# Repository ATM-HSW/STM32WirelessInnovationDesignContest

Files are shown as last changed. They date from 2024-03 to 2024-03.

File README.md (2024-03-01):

# STM32 Wireless Innovation Design Contest

## Universal room sensor for various MCUs with communication interfaces

### Teaser:

As part of this project, a multi-sensor module is being developed with which various room parameters can be measured. In addition to the usual measured values of temperature, humidity and air pressure, the indoor air quality is also to be determined using VOC and CO2 sensors. A multi-channel light measurement is also to be carried out.

The sensor module should be as compact as possible and be able to be used universally on various MCU platforms via the I2C bus.

Programming should be as simple as possible using existing libraries and software environments, e.g. Arduino environment, Micro- or CircuitPython.

The choice in this competition fell on the relatively new STM32WB52xx platform. Experience with other STM Nucleo boards forms the basis for this project.

### Project Details

The universal room sensor is being developed as the most universal platform possible to measure the parameters of the environment, i.e. rooms such as a lecture theatres, seminar rooms or offices. It should also be possible to test different MCU variants with different communication interfaces and different software environments.

The aim is to equip the rooms of a university with the room sensor. Staff and students should be able to access the sensor values. In future, however, it should also be possible to use the values for needs-based and energy-efficient control of the rooms and integration into the Building Information Management (BIM) system.

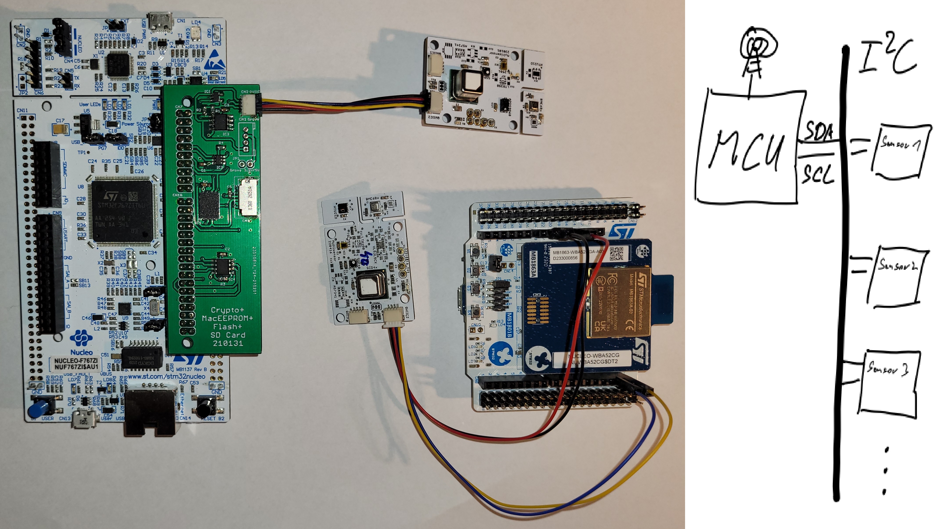
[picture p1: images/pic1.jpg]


### System Overview

As the chosen platform Nucleo-WBA52 is still relatively new, the software support is not yet as extensive as with hardware platforms that have been available for longer. The aim of this project is not the direct use of STM's Cube Packages but of development environments such as Arduino and Circuit-/Micropython. The Python variants are not yet available at the release date 01.03.2024. The Arduino platform STM32duino [sta1] has contained the extension for the STM32WBA family in the main branch since 29/02/2024. However, the planned release 2.8 is not yet available at the time of publication. According to the instructions [sta2], however, a Git branch can also be used for development.

In order to be able to compare the implementation with Circuit- and Micropython, the MultiSensor module was used with the Nucleo-F767 platform, which has been available for some time. This platform can be used in all three environments.

A test shield from a previous project is used to connect the MultiSensor module to the Nucleo-F7676. Only the QWIIC (I2C) connector is used. To connect to the Nucleo-WBA52, a shield has been developed that only provides a QWIIC connector. Due to component availability, the design only includes a short socket strip on which the 3.3V connection is missing. Therefore a 3.3V LDO is used on the board. As this board could not be finalised at the time of publication, a standard QWIIC cable with male jumpers is used to connect the Nucleo board with the MultiSensor module.

Both adapter boards were designed with eagle. The CAD data is available in the project repository at Github (link under software used)

### Sensor hardware

The MultiSensor module contains various sensors for measuring environmental parameters. All sensors are connected to the MCU via an I2C bus. The sensors were selected based on the availability of the ICs and the availability of open source drivers for the development environments analysed. The I2C bus can be used in two ways: on a pin header and via dual QUIIC sockets. As there is an overlap between the I2C addresses of the APDS9960 and AS7341 light sensors, two I2C buses are used. However, both buses are connected by default via solder jumpers. The two solder jumpers only need to be disconnected if both light sensors are to be used. In this case, the APDS9960 is no longer available at the QWIIC sockets, but only via the pin headers.

The only special mechanical feature of the board layout is the thermal decoupling of the two temperature sensors BME680 and HTU21 on the left-hand side of the board.

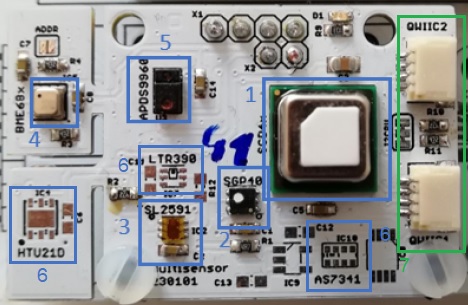
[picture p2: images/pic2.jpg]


- Sensor 1: CO2 sensor SCD4x

The SCD-4x CO2 sensors from Sensirion have a measuring range of 400-5000 ppm with different accuracies between ±40 and ±75ppm, depending on the exact type. Versions 40, 41 and 42 are pin and software compatible. As the sensor is based on a photoacoustic measuring principle, it is relatively small and energy-saving compared to older sensors based on the non-dispersive infrared sensor principle [MP]. The ambient air in the measuring chamber is irradiated with a defined light pulse (wavelength approx. 4.3µm). The gas molecules absorb the light. The result is an increase in pressure in the measuring cell. The increase in pressure generates sound waves that can be picked up by a microphone.

For good indoor air quality, the CO2 value should be below 800ppm. The maximum guideline value for indoor spaces is 1500ppm [CIK]. At this value, signs of fatigue can already occur.

- Sensor 2: SGP4x

The SGP-40 and 41 indoor air quality sensors from Sensirion measure volatile organic compounds (VOCs) such as sweat, urea, paint and cleaning agents. The 41 model can also detect nitrogen oxides (NOx). The sensor is a chemical metal oxide semiconductor gas sensor. The surface of the sensor that comes into contact with the gas to be detected is coated with a metal oxide. This changes its resistance, which can be read out as a raw value.

The raw value of the sensor is mapped by a filter function to a measuring range of 0-500, the IAQ index. A value of 100 corresponds to uncontaminated room air.

- Sensor 3: TSL2591 light sensor

The measuring principle of the TSL2591 light sensor from ams is based on two light-to-digital converters that convert the incoming light intensity into electrical signals using photodiodes. The light irradiation changes the electrical voltage measured by the photodiode or the current flowing through the diode. The sensor's two photodiodes measure the part of the light visible to humans and the infrared spectrum in two channels.

- Sensor 4: Temperature, humidity, pressure and gas sensor BME680

The BME680 combination sensor from Bosch is a MEMS sensor that measures the ambient air parameters of temperature, humidity and air pressure. A gas sensor is also included.

- Sensor 5: APDS9960 light sensor

Like sensor 3, the APDS9960 light sensor from Avago can measure light intensity. Colour measurement is also possible. However, in this project the sensor is used for contactless operation, as it can also be used as a proximity sensor and for gesture recognition such as UP-DOWN-RIGHT-LEFT.

- Sensors 6:

The photo shows an assembly variant in which other sensors have not been fitted. The HTU21 is a sensor for temperature and humidity comparable to the BME680. Ambient light measurement can be extended with the two light sensors LTR390 and AS7341. The LTR390 can measure ultraviolet light in two spectra. The AS7341 is sensitive in the visible and near IR range, similar to the TSL2561, but is divided into 11 channels so that colour temperatures can also be determined.

The circuit and layout were designed using eagle. The respective data sheet information and open hardware layouts were generally used from the Adafruit Github account [ada]. The CAD data is available in the project repository at Github (link under Software used)

The CAD data is available on the car's Github account. The hardware is fully tested, including the sensors missing in the figure above.

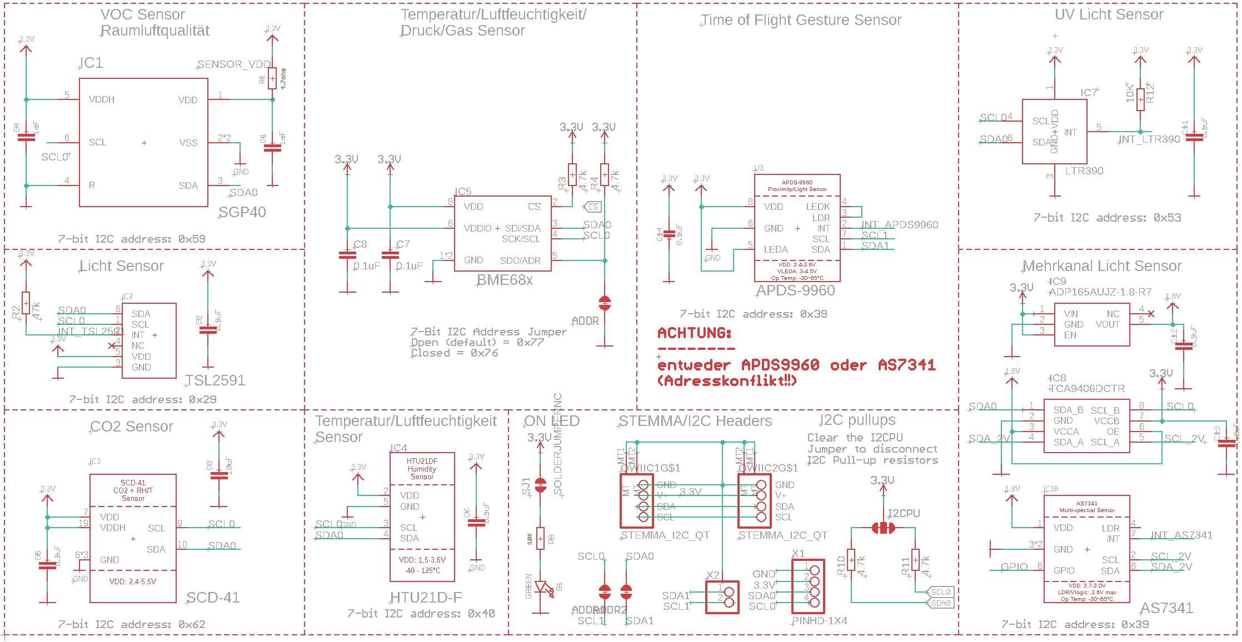
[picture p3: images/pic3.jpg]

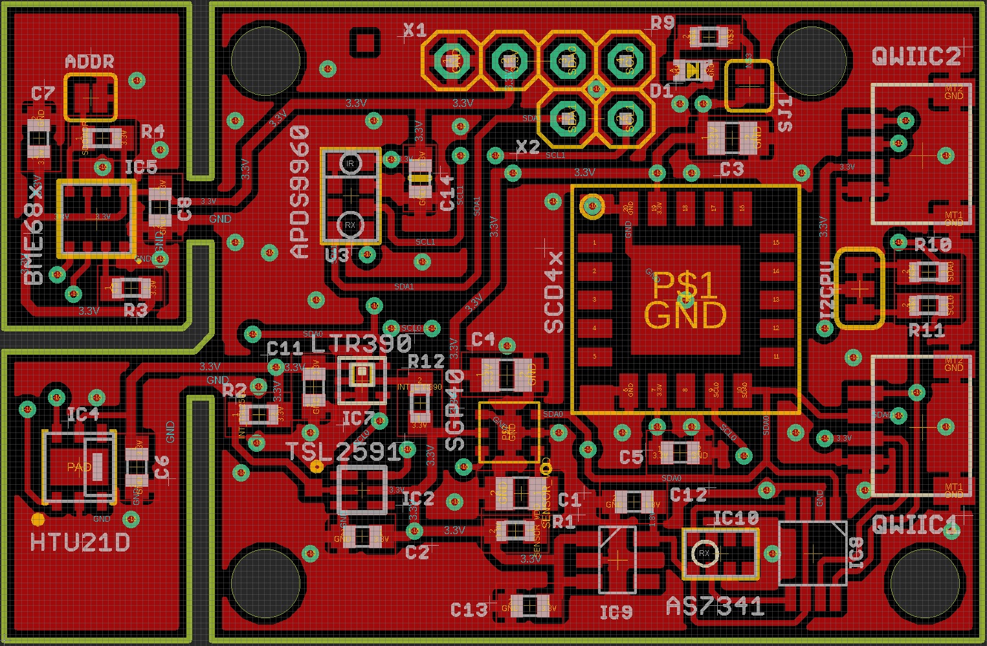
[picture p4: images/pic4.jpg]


### Software

- Variant 1: Nucleo-F767 and Micropython

The implementation with Micropython is only a proof of concept due to limitations of the current Micropython implementation. Usable libraries exist for the BME680, HTU21, SGP40 and SCP4x sensors. The Ethernet interface is directly supported by Micropython. A connection to Thingsboard as an IOT cloud is possible.

As expected, the implementation under Micropython is very quick and easy. The firmware can be flashed with the onboard ST-Link. Utilising existing libraries, the sensors are ready for operation in a short time.

However, the division of the flash has proved to be a significant disadvantage. With the default setting. Of the 2Mbyte flash, only around 80kByte are available for Python code. Most of the rest is reserved for the firmware, although this amount is far from being required.

- Variant 2: Nucleo-F767 and Circuitpython

The statements made about variant 1 also apply to variant 2. As essentially only sensors that are also sold by Adafruit are used, the software support is even simpler than under Micropython. However, the same restriction also applies to Circuitpython: the flash size for the Python sources is too small. Another disadvantage is the lack of network support.

#### Summary of variants 1 and 2:

If it were not for the limitation of the flash size, Micro- and Circuitpython could be very good development environments for the use of the MultiSensor. The lack of Ethernet support in Circuitpython is an exclusion criterion if a cloud connection is required.

The MultiSensor, including a cloud connection, could be fully implemented with another MCU platform using the Circuitpyhon environment.

Porting for the NUCLEO-WBA52 platform has not yet taken place, but it can be assumed that this platform can also be used very well under Python. The disadvantage of the flash size is solvable, as there is sufficient unused flash memory available.

- Variant 3: Nucleo-F767 and STM32duino

As the port for the STM32WBAxx family was not yet available at the start of the project, an initial implementation was carried out on the Nucleo-F767. Available Arduino libraries were used for the sensors. With a few minor adjustments to these libraries, all sensors could be used.

- Variant 4: Nucleo-WBA52 and STM32duino

The application developed for variant 3 could be used directly for variant 4. It was only necessary to adapt the I2C pins.

#### Summary of variants 3 and 4:

As the Arduino environment has existed for a very long time, there are many examples, drivers etc. available. Not everything is immediately usable. But changes are usually limited. Due to the unavoidable compile-link-flash cycle, development is significantly less agile than with a Python variant. However, the usage is also possible with an acceptable amount of effort.

The sources of the implementations are available in the project repository at Github (link under Software used).

## Literature:

[ad] Adafruit Industries, LLC. url: www.adafruit.com

[cik] CIK Solutions. Kohlenstoffdioxid in Räumen messen und überwachen. url: https://www.cik-solutions.com/anwendungen/co2-im-innenraum/

[mp] MIROSLAV PISKOR. SCD4x – der kleinste CO2-Sensor. Hrsg. von SOS electronic. 2021-04-15. url: https://www.soselectronic.com/de/articles/sensirion/scd4x-der-kleinste-co2-sensor-2559

[sta1] STM32duino project repository. url: https://github.com/stm32duino

[sta2] STM32duino git repo integratio into Arduino IDE. url: https://github.com/stm32duino/Arduino_Core_STM32/wiki/Using-git-repository

## Used Software

STM32duino

https://github.com/stm32duino/Arduino_Core_STM32/archive/a5135d476018c1d1ea7b33afe86ae29aa416cbf7.zip

Circuitpython

https://downloads.circuitpython.org/bin/nucleo_f767zi/de_DE/adafruit-circuitpython-nucleo_f767zi-de_DE-8.2.10.bin

Micropython

https://micropython.org/resources/firmware/NUCLEO_F767ZI-20240222-v1.22.2.hex

Project sourcen

https://github.com/ATM-HSW/STM32WirelessInnovationDesignContest

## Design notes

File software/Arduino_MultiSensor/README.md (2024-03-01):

Used Libraries:

HTU21: https://github.com/adafruit/Adafruit_HTU21DF_Library (v1.1.2)
BME68x: https://github.com/adafruit/Adafruit_BME680 (v2.0.4)
SGP40: https://github.com/adafruit/Adafruit_SGP40 (v1.1.3)
SCD40: https://github.com/Sensirion/arduino-i2c-scd4x (v0.4.0)
TSL2591: https://github.com/adafruit/Adafruit_TSL2591_Library (v1.4.5)

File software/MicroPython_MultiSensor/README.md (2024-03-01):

Used Libraries:

HTU21: https://github.com/Kleity/HTU21D-Micropython-ESP32
BME68x: https://github.com/robert-hh/BME680-Micropython
SGP40: https://github.com/agners/micropython-sgp40
SCD40: https://github.com/mikan/rpi-pico-scd4x

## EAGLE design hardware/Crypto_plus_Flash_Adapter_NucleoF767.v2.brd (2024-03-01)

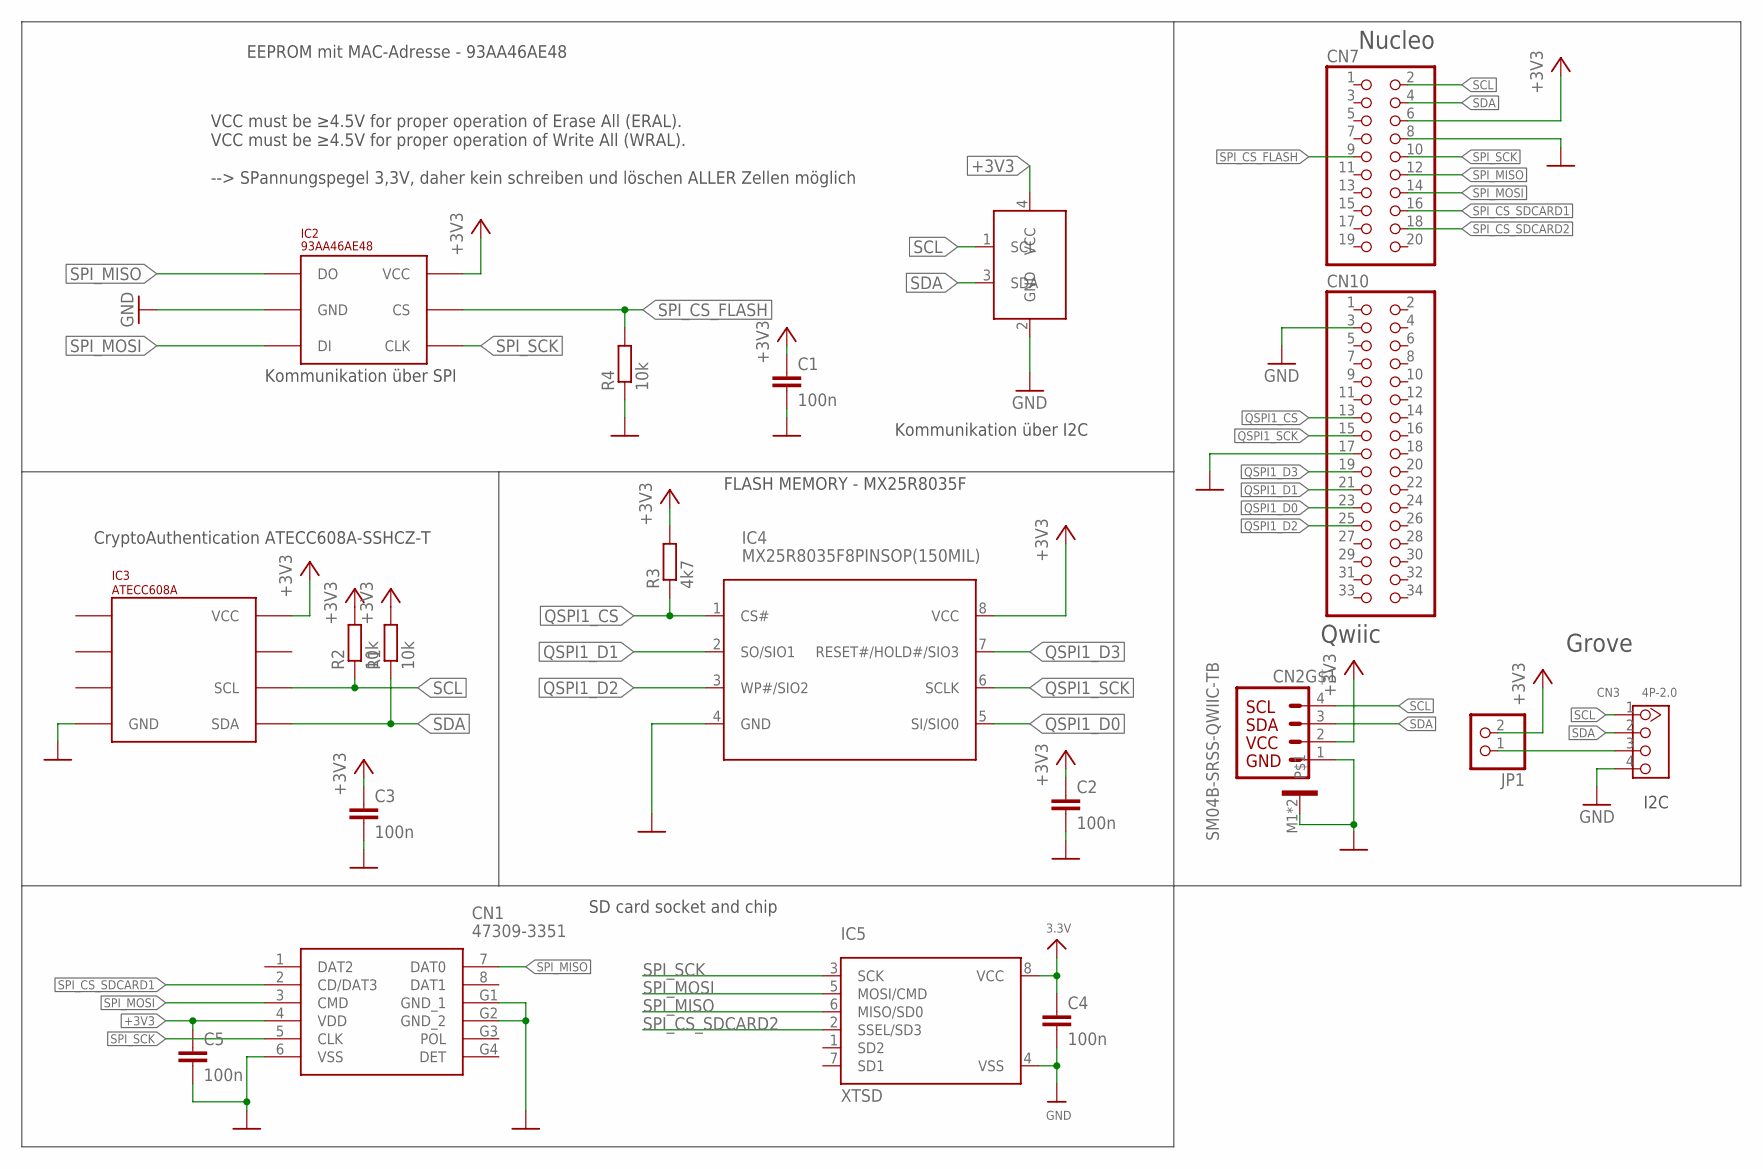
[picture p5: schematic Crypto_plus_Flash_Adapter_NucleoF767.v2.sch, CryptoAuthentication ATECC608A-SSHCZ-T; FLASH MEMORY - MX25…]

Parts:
C1, C2, C3, C4, C5: 100n; C0603
CN1: 47309-3351; 473093351
CN2: SM04B-SRSS-QWIIC-TB; SM04B-SRSS-TB
CN3: 4P-2.0; HW4-2.0
CN7: PINHD-2X10; 2X10
CN10: PINHD-2X17; 2X17
IC1: I2CEEPROM_24AA02E48; SOT23-5L
IC2: 93AA46AE48
IC3: ATECC608A; SOIC8
IC4: MX25R8035F8PINSOP(150MIL); SOIC127P600X175-8
IC5: XTSD; LGA8_8X6
JP1: PINHD-1X2; 1X02
R1, R2, R4: 10k; R0603
R3: 4k7; R0603

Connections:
+3V3: C1.1, C2.1, C3.1, C4.1, C5.1, CN1.4 (VDD), CN2.2, CN7.6, IC1.4 (VCC), IC2.P$6 (VCC), IC3.8 (VCC), IC4.8 (VCC), IC5.8 (VCC), JP1.2, R1.2, R2.2, R3.2
GND: C1.2, C2.2, C3.2, C4.2, C5.2, CN1.6 (VSS), CN1.G1 (GND_1), CN1.G2 (GND_2), CN2.1, CN2.M1, CN2.M2, CN3.4, CN7.8, CN10.17, IC1.2 (GND), IC2.P$2 (GND), IC3.4 (GND), IC4.4 (GND), IC5.4 (VSS), R4.1
unnamed: CN3.3, JP1.1
QSPI1_CS: CN10.13, IC4.1 (CS#), R3.1
QSPI1_D0: CN10.23, IC4.5 (SI/SIO0)
QSPI1_D1: CN10.21, IC4.2 (SO/SIO1)
QSPI1_D2: CN10.25, IC4.3 (WP#/SIO2)
QSPI1_D3: CN10.19, IC4.7 (RESET#/HOLD#/SIO3)
QSPI1_SCK: CN10.15, IC4.6 (SCLK)
SCL: CN2.4, CN3.1, CN7.2, IC1.1 (SCL), IC3.6 (SCL), R2.1
SDA: CN2.3, CN3.2, CN7.4, IC1.3 (SDA), IC3.5 (SDA), R1.1
SPI_CS_FLASH: CN7.9, IC2.P$5 (CS), R4.2
SPI_CS_SDCARD1: CN1.2 (CD/DAT3), CN7.16
SPI_CS_SDCARD2: CN7.18, IC5.2 (SSEL/SD3)
SPI_MISO: CN1.7 (DAT0), CN7.12, IC2.P$1 (DO), IC5.6 (MISO/SD0)
SPI_MOSI: CN1.3 (CMD), CN7.14, IC2.P$3 (DI), IC5.5 (MOSI/CMD)
SPI_SCK: CN1.5 (CLK), CN7.10, IC2.P$4 (CLK), IC5.3 (SCK)

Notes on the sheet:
VCC must be ≥4.5V for proper operation of Erase All (ERAL). VCC must be ≥4.5V for proper operation of Write All (WRAL). --> SPannungspegel 3,3V, daher kein schreiben und löschen ALLER Zellen möglich
Kommunikation über SPI
CryptoAuthentication ATECC608A-SSHCZ-T
FLASH MEMORY - MX25R8035F
EEPROM mit MAC-Adresse - 93AA46AE48
Kommunikation über I2C
SD card socket and chip
Qwiic
I2C
Grove
Nucleo

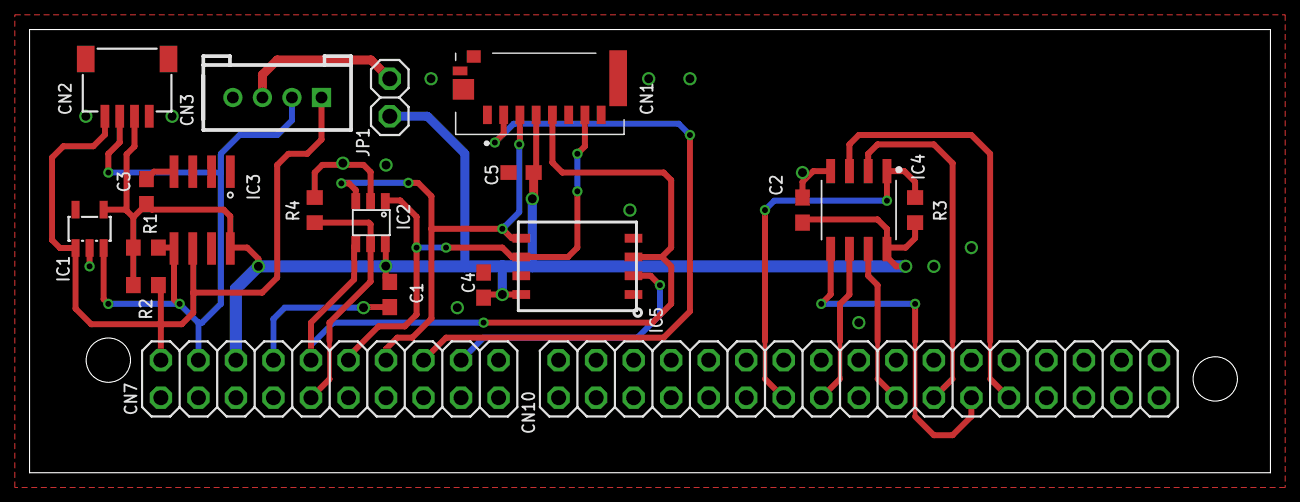
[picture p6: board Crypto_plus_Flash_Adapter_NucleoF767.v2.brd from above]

Board: 4 copper layers, 84.0 x 30.0 mm, 20 parts (0 on the bottom side), 17 nets.

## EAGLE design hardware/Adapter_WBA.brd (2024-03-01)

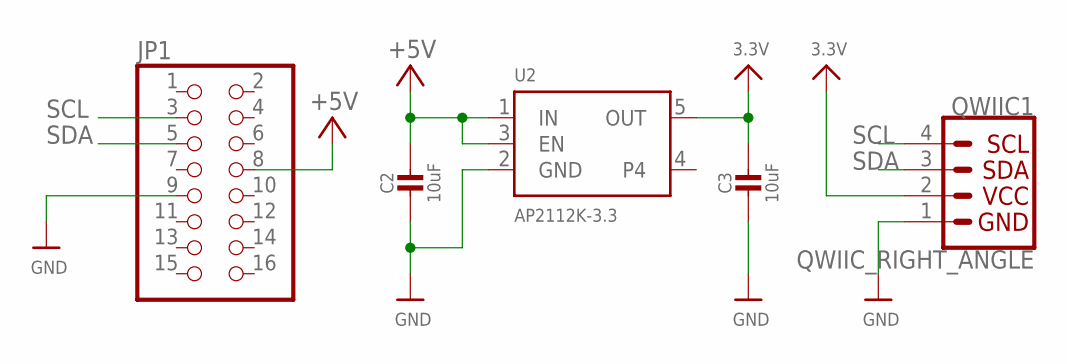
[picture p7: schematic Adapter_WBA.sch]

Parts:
C2, C3: 10uF; 0805-NO
JP1: PINHD-2X8; 2X08
QWIIC1: QWIIC_RIGHT_ANGLE; JST04_1MM_RA
U2: AP2112K-3.3; SOT23-5

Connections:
3.3V: C3.1, QWIIC1.2, U2.5 (OUT)
+5V: C2.1, JP1.8, U2.1 (IN), U2.3 (EN)
GND: C2.2, C3.2, JP1.9, QWIIC1.1, U2.2 (GND)
SCL: JP1.3, QWIIC1.4
SDA: JP1.5, QWIIC1.3

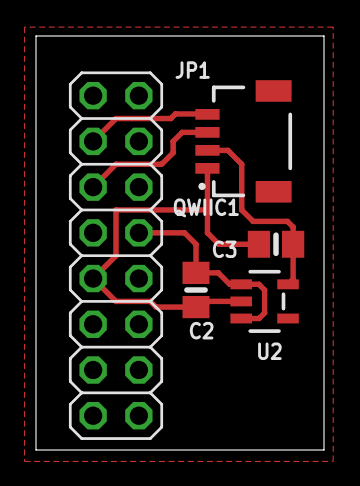
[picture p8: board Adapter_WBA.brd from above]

Board: 2 copper layers, 16.0 x 23.0 mm, 5 parts (0 on the bottom side), 5 nets.

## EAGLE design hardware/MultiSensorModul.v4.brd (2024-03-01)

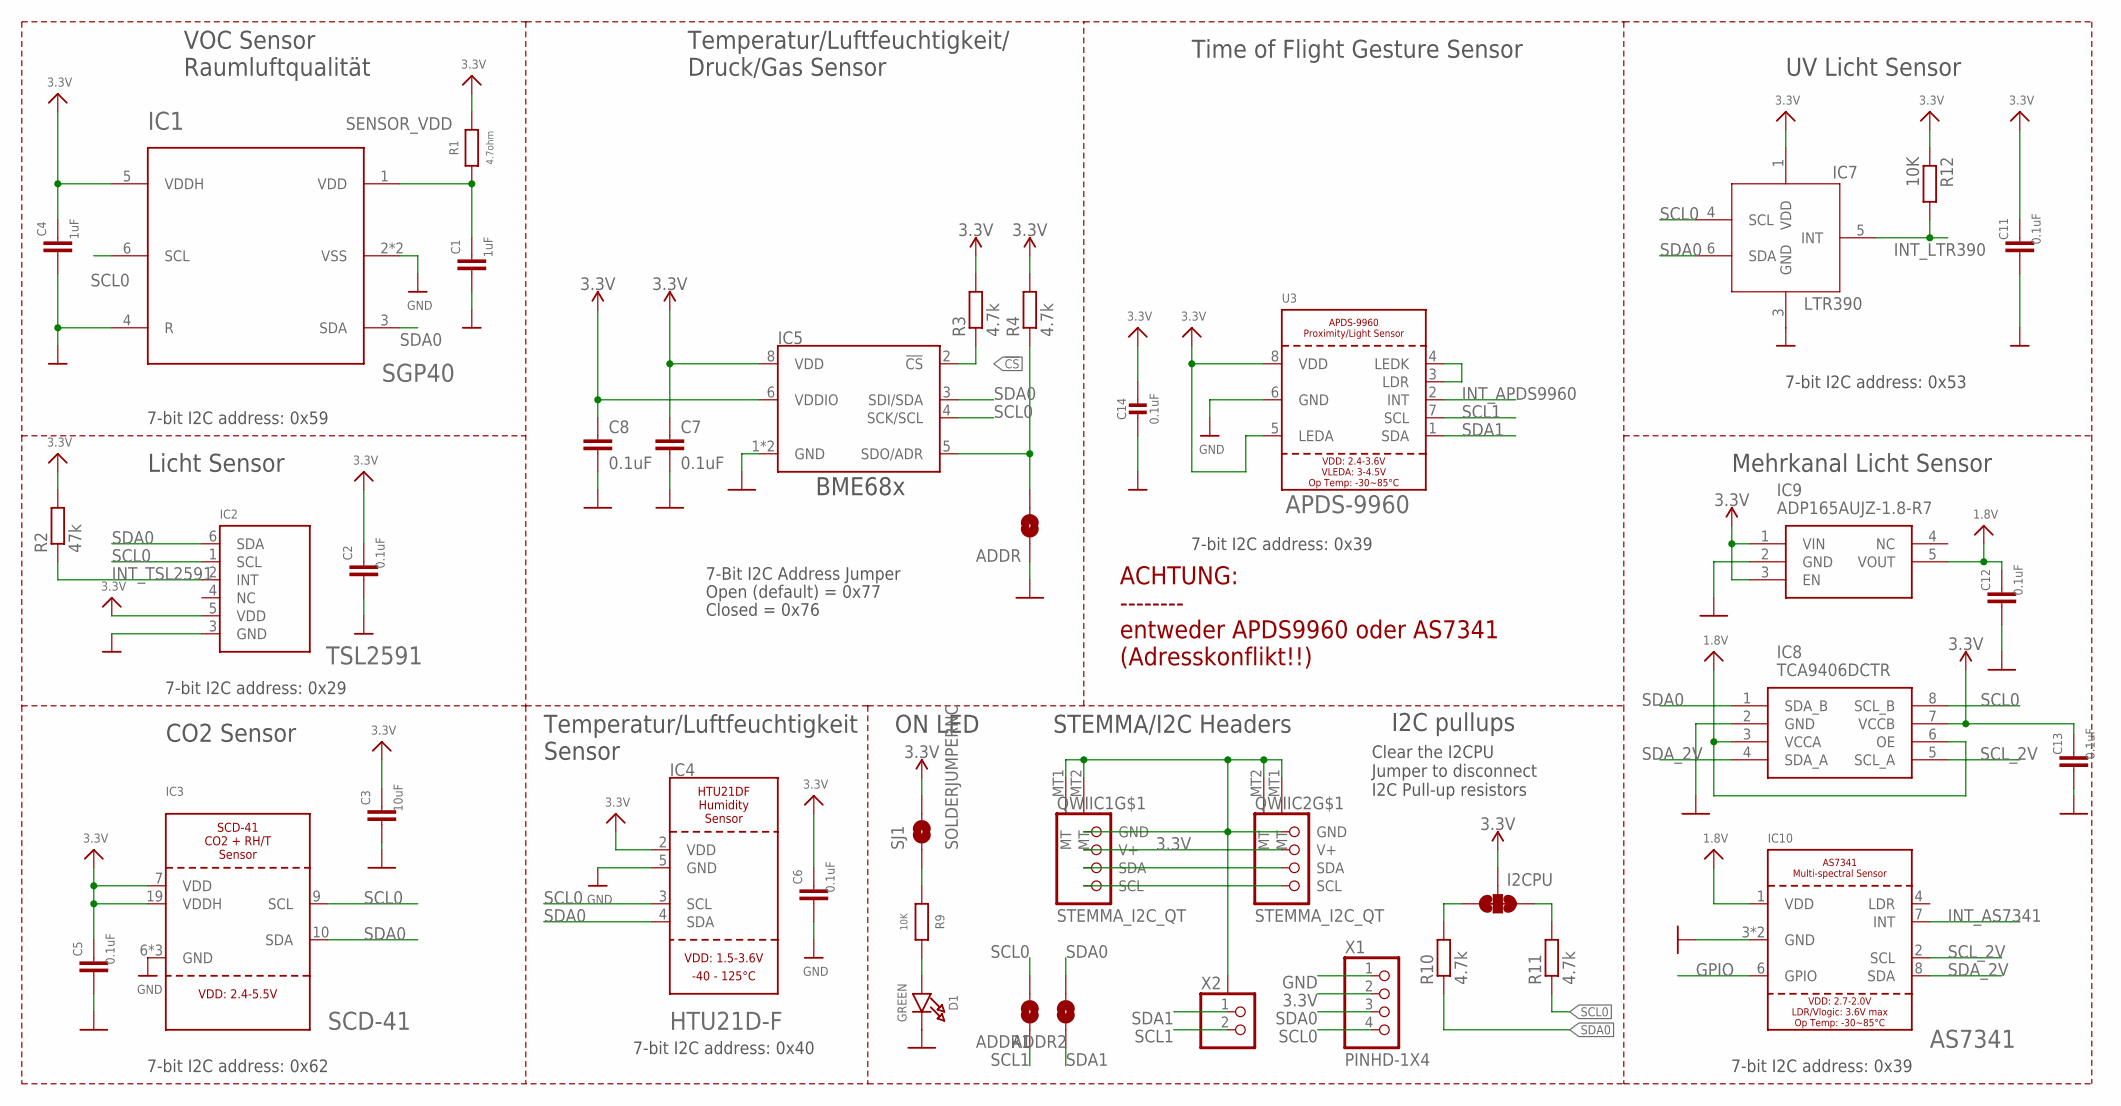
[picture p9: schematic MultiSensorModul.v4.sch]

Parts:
ADDR, ADDR1, ADDR2: JUMPER-SMT_2_NO_SILK; SMT-JUMPER_2_NO_SILK
C1, C4: 1uF; C0805
C2, C5, C6, C7, C8, C11, C12, C13: 0.1uF; C0603
C3: 10uF; C0805
C14: 0.1uF; 0603-NO
D1: GREEN; CHIPLED_0603_NOOUTLINE
I2CPU: I2C PU; SMT-JUMPER_3_2-NC_TRACE_SILK
IC1: SGP40; SGP30
IC2: TSL2591; DFN6_TAOS
IC3: SCD-41; SCD41
IC4: HTU21D-F; HTU21DF
IC5: BME680 Air Quality Sensor; LGA3.0X3.0
IC7: LTR390
IC8: TCA9406DCTR; SOP65P400X130-8N
IC9: ADP165AUJZ-1.8-R7; SOT95P280X100-5N
IC10: AS7341
QWIIC1, QWIIC2: STEMMA_I2C_QT; JST_SH4
R1: 4.7ohm; R0603
R2: 47k; R0603
R3, R4, R10, R11: 4.7k; R0603
R9, R12: 10K; R0603
SJ1: SOLDERJUMPERNC; SJ_2S
U3: APDS-9960
X1: PINHD-1X4; 1X04
X2: PINHD-1X2; 1X02

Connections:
1.8V: C12.1, IC8.3 (VCCA), IC8.6 (OE), IC9.5 (VOUT), IC10.1 (VDD)
3.3V: C2.1, C3.1, C4.1, C5.1, C6.1, C7.1, C8.1, C11.1, C13.1, C14.1, I2CPU.2, IC1.5 (VDDH), IC2.5 (VDD), IC3.7 (VDD), IC3.19 (VDDH), IC4.2 (VDD), IC5.6 (VDDIO), IC5.8 (VDD), IC7.1 (VDD), IC8.7 (VCCB), IC9.1 (VIN), IC9.3 (EN), QWIIC1.2 (V+), QWIIC2.2 (V+), R1.2, R2.2, R3.2, R4.2, R12.1, SJ1.2, U3.5 (LEDA), U3.8 (VDD), X1.2
!CS: IC5.2 (!CS), R3.1
GND: ADDR.1, C1.2, C2.2, C3.2, C4.2, C5.2, C6.2, C7.2, C8.2, C11.2, C12.2, C13.2, C14.2, D1.C, IC1.2 (VSS), IC1.4 (R), IC1.P$7 (VSS), IC2.3 (GND), IC3.6 (GND), IC3.20 (GND), IC3.P$1 (GND), IC4.5 (GND), IC5.1 (GND), IC5.7 (GND), IC7.3 (GND), IC8.2 (GND), IC9.2 (GND), IC10.3 (GND), IC10.5 (GND), QWIIC1.1 (GND), QWIIC1.MT1 (MT), QWIIC1.MT2 (MT), QWIIC2.1 (GND), QWIIC2.MT1 (MT), QWIIC2.MT2 (MT), U3.6 (GND), X1.1
GPIO: IC10.6 (GPIO)
INT_APDS9960: U3.2 (INT)
INT_AS7341: IC10.7 (INT)
INT_LTR390: IC7.5 (INT), R12.2
INT_TSL2591: IC2.2 (INT), R2.1
unnamed: D1.A, R9.2
unnamed: U3.3 (LDR), U3.4 (LEDK)
unnamed: R9.1, SJ1.1
unnamed: I2CPU.3, R10.2
unnamed: I2CPU.1, R11.2
SCL0: ADDR1.2, IC1.6 (SCL), IC2.1 (SCL), IC3.9 (SCL), IC4.3 (SCL), IC5.4 (SCK/SCL), IC7.4 (SCL), IC8.8 (SCL_B), QWIIC1.4 (SCL), QWIIC2.4 (SCL), R11.1, X1.4
SCL1: ADDR1.1, U3.7 (SCL), X2.2
SCL_2V: IC8.5 (SCL_A), IC10.2 (SCL)
SDA0: ADDR2.2, IC1.3 (SDA), IC2.6 (SDA), IC3.10 (SDA), IC4.4 (SDA), IC5.3 (SDI/SDA), IC7.6 (SDA), IC8.1 (SDA_B), QWIIC1.3 (SDA), QWIIC2.3 (SDA), R10.1, X1.3
SDA1: ADDR2.1, U3.1 (SDA), X2.1
SDA_2V: IC8.4 (SDA_A), IC10.8 (SDA)
SDO/ADR: ADDR.2, IC5.5 (SDO/ADR), R4.1
SENSOR_VDD: C1.1, IC1.1 (VDD), R1.1

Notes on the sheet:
STEMMA/I2C Headers
ON LED
7-Bit I2C Address Jumper
Open (default) = 0x77
Closed = 0x76
Clear the I2CPU Jumper to disconnect I2C Pull-up resistors
7-bit I2C address: 0x39
Time of Flight Gesture Sensor
I2C pullups
7-bit I2C address: 0x40
7-bit I2C address: 0x62
7-bit I2C address: 0x29
7-bit I2C address: 0x59
7-bit I2C address: 0x53
ACHTUNG: -------- entweder APDS9960 oder AS7341 (Adresskonflikt!!)
VOC Sensor Raumluftqualität
Temperatur/Luftfeuchtigkeit/ Druck/Gas Sensor
UV Licht Sensor
Mehrkanal Licht Sensor
Temperatur/Luftfeuchtigkeit Sensor
CO2 Sensor
Licht Sensor
BME68x

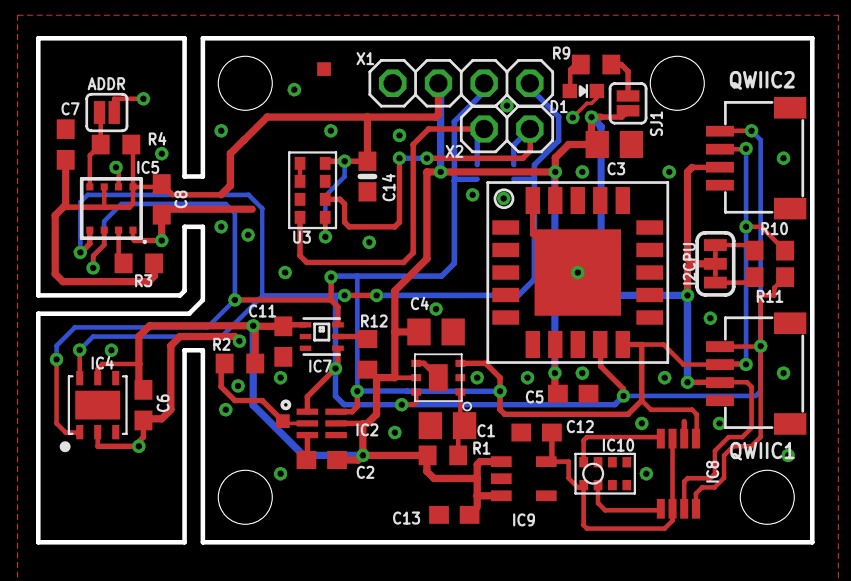
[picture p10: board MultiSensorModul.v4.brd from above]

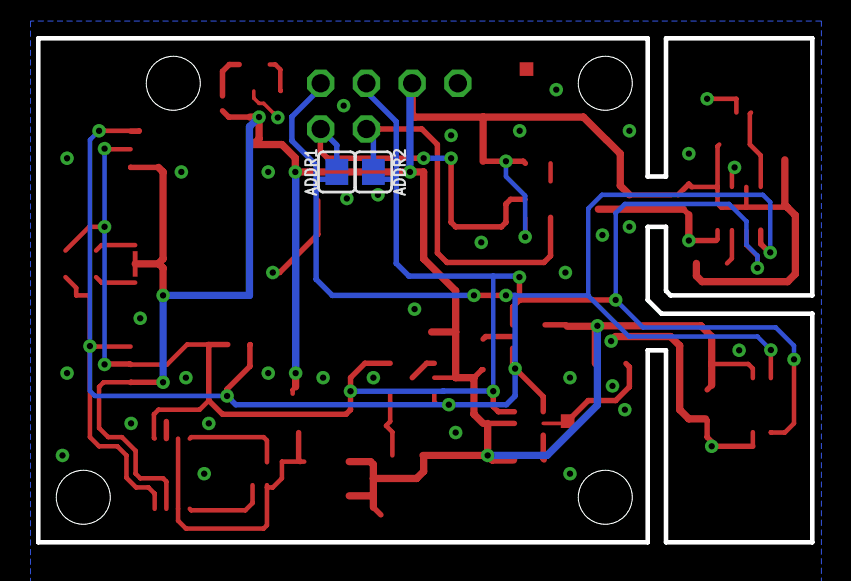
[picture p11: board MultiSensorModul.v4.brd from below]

Board: 2 copper layers, 43.0 x 28.0 mm, 40 parts (2 on the bottom side), 19 nets.

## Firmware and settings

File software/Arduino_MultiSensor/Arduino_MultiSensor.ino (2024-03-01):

#include "Adafruit_SGP40.h"
#include "Adafruit_HTU21DF.h"
#include "Adafruit_BME680.h"
#include "SensirionI2CScd4x.h"
#include "Adafruit_TSL2591.h"

#define SEALEVELPRESSURE_HPA (1013.25)

Adafruit_SGP40 sgp;
Adafruit_HTU21DF htu;
Adafruit_BME680 bme;
Adafruit_TSL2591 tsl = Adafruit_TSL2591(2591); // pass in a number for the sensor identifier (for your use later)
SensirionI2CScd4x scd4x;
uint16_t error;
char errorMessage[256];

bool bsgp=true, bhtu=true, bbme=true, bscd = true, btsl = true; 

void printUint16Hex(uint16_t value) {
    Serial.print(value < 4096 ? "0" : "");
    Serial.print(value < 256 ? "0" : "");
    Serial.print(value < 16 ? "0" : "");
    Serial.print(value, HEX);
}

void printSerialNumber(uint16_t serial0, uint16_t serial1, uint16_t serial2) {
    Serial.print("Serial: 0x");
    printUint16Hex(serial0);
    printUint16Hex(serial1);
    printUint16Hex(serial2);
    Serial.println();
}

void setup() {
  Serial.begin(115200);
  while (!Serial) { delay(10); } // Wait for serial console to open!

  Serial.println("room sensor test");

  if (!sgp.begin()){
    Serial.println("SGP4x sensor not found");
    bsgp = false;
  }

  if(bsgp) {
    Serial.print("SGP4x serial #");
    printSerialNumber(sgp.serialnumber[0], sgp.serialnumber[1], sgp.serialnumber[2]);
  }

  if (!htu.begin()) {   // Set to 0x45 for alternate i2c addr
    Serial.println("HTU21 sensor not found");
    bhtu = false;
  }

  if (!bme.begin()) {
    Serial.println("BME680 sensor not found");
    bbme = false;
  } else {
    bme.setTemperatureOversampling(BME680_OS_8X);
    bme.setHumidityOversampling(BME680_OS_2X);
    bme.setPressureOversampling(BME680_OS_4X);
    bme.setIIRFilterSize(BME680_FILTER_SIZE_3);
    bme.setGasHeater(320, 150); // 320*C for 150 ms
  }

  if(!tsl.begin()) {
    Serial.println(F("TSL2591 sensor not found"));
    btsl = false;
  } else {
    tsl.setGain(TSL2591_GAIN_MED);
    tsl.setTiming(TSL2591_INTEGRATIONTIME_300MS);
  }

  scd4x.begin(Wire);
  // stop potentially previously started measurement
  if (scd4x.stopPeriodicMeasurement()) {
      Serial.print("SCD4x: Error trying to execute stopPeriodicMeasurement(): ");
  }

  uint16_t serial0;
  uint16_t serial1;
  uint16_t serial2;
  if (scd4x.getSerialNumber(serial0, serial1, serial2)) {
    Serial.println("SCD4x sensor not found");
    bscd = false;
  } else {
    Serial.print("SCD4x serial #");
    printSerialNumber(serial0, serial1, serial2);
  }

  if(bscd) {
    // Start Measurement
    error = scd4x.startPeriodicMeasurement();
    if (error) {
        Serial.print("Error trying to execute startPeriodicMeasurement(): ");
        errorToString(error, errorMessage, 256);
        Serial.println(errorMessage);
    }
  }

}

void loop() {
  uint16_t sraw;
  int32_t voc_index;
  float t=25, h=50, p, alt;
  uint16_t co2 = 0;
  bool isDataReady = false;
  
  if(bhtu) {
    Serial.print("HTU21:\t");
    t = htu.readTemperature();
    Serial.print("Temp *C = "); Serial.print(t); Serial.print("\t\t");
    h = htu.readHumidity();
    Serial.print("Hum. % = "); Serial.println(h);
    //Serial.println();
  }

  if(bbme) {
    if(bme.performReading()) {
      Serial.print("BME68X:\t");
      t = bme.temperature;
      Serial.print("Temp *C = "); Serial.print(t); Serial.print("\t\t");
      h = bme.humidity;
      Serial.print("Hum. % = "); Serial.print(h); Serial.print("\t\t");
      p = bme.pressure / 100.0;
      Serial.print("Press. hPa = "); Serial.print(p); Serial.print("\t\t");
      alt = bme.readAltitude(SEALEVELPRESSURE_HPA);
      Serial.print("Approx. Altitude m = "); Serial.println(alt);
      //Serial.println();
    }
  }

  if(btsl) {
    Serial.print("TSL2561:");
    uint32_t lum = tsl.getFullLuminosity();
    uint16_t ir, full;
    ir = lum >> 16;
    full = lum & 0xFFFF;
    Serial.print("IR: "); Serial.print(ir); Serial.print("\t\t");
    Serial.print("Full: "); Serial.print(full);  Serial.print("\t\t");
    Serial.print("Visible: "); Serial.print(full - ir);  Serial.print("\t\t\t");
    Serial.print("Lux: "); Serial.println(tsl.calculateLux(full, ir), 6);
    //Serial.println();
  }

  if(bsgp) {
    Serial.print("SGP4x:\t");
    sraw = sgp.measureRaw(t, h);
    Serial.print("Raw measurement: "); Serial.print(sraw);  Serial.print("\t");

    voc_index = sgp.measureVocIndex(t, h);
    Serial.print("Voc Index: "); Serial.println(voc_index); 
    //Serial.println();
  }

  if(bscd) {
    scd4x.getDataReadyFlag(isDataReady);
    if(isDataReady) {
      Serial.print("SCD4x:\t");
      if (scd4x.readMeasurement(co2, t, h)) {
        Serial.print("Error trying to execute readMeasurement(): ");
      } else if (co2 == 0) {
        Serial.println("Invalid sample detected, skipping.");
      } else {
        Serial.print("Co2 ppm = "); Serial.println(co2);
        //Serial.println();
      }
    }
  }

  Serial.println("==================================================================\n");


  delay(1000);
}

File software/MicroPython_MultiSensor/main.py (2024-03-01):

from machine import I2C
from mpy_htu21 import mpy_htu21
from mpy_bme68x import mpy_bme68x
from mpy_sgp40 import mpy_sgp40


i2c=I2C(scl='B8', sda='B9')
i2c.scan()

htu21=mpy_htu21(i2c)
print("htu21")
print(htu21.temperature)
print(htu21.humidity)

bme=mpy_bme68x(i2c)
print("bme68x")
print(bme.temperature)
print(bme.humidity)
print(bme.pressure)
print(bme.gas)

sgp=mpy_sgp40(i2c)
print("sgp40")
print(sgp.measure_raw(htu21.humidity, htu21.temperature))

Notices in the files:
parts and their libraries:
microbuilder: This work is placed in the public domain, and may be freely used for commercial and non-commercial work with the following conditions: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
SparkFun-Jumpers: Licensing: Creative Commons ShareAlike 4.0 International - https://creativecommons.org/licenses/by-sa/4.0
